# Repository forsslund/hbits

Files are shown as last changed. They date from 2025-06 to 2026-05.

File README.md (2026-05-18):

# Haptic Bits Lab Repository
here you find all the necessary files to be able to eithe build your own or repair a Haptic Bit. If you want to know more what a haptic bit is or the Haptic Bits Lab, have a look here: (https://hbits.forsslundsystems.com)

## Software Recommendation for MIDI Recording
The are myriads of choices of MIDI recording software. Here's a list of some that work great with the bits:
- Chataigne: A multipurpose sequencer that also supports MIDI. You'll find a template in the folder "MIDI". It's configured to record all bits in one kit. https://benjamin.kuperberg.fr/chataigne/en
- Signal: Online MIDI sequencer that runs great on Chrome (note: doesn't work with Safari): https://signalmidi.app/edit
- MIDI Bitslab: Our own attempt of a recording environment that runs great on Chrome (note: doesn't work with Safari). It emphasises sketching and direct recording and has some features to make dynamic patches. : https://github.com/somaBits/Midi_BitLab/

## Firmware
The bits are driven by an ESP32. If you would like to make changes to the firmware you are free to download this repository and open it in VS code with the platform.io plugin.

This can be usefull if for example you wish to customise the haptic patterns for the vibration bits.

## Do it Yourself
The Haptic Bits Lab is designed to be built by anyone that has access to a 3D printer and laser cutter. The carrier PCB are produced by PCBway and can be order semi-populated with SMD parts via this link: (https://www.pcbway.com/project/shareproject/Haptic_Bits_Lab_Carrier_PCB_semi_populated_7a38576c.html)

This Bill of material contains all the third-party parts needed to create the bits: (https://docs.google.com/spreadsheets/d/1yp4ojiJQZM4SgLv2cJ91fp2alQbMcc3hZMMRH2068LM/edit?usp=sharing)

The 3D model of the enclosure are modelled in Fusion 360 and can be downloaded here:

|Name | Link | Image |
| --- | --- | --- |
| AIR enclosure | https://a360.co/3LH06NW or [3MF file for printing ](hardware/3d_models/HBL_AIR.3mf)| AIR |
| VIBE / HEAT enclosure | https://a360.co/4b2XGnf or [3MF file for printing ](hardware/3d_models/HBL_VIBEHEAT.3mf) | VIBE:HEAT |
| Rotary Knob | https://a360.co/4jEkBaE or [3MF file for printing ](hardware/3d_models/HBL KNOBS_6x.3mf) | Knob |
| LED Ring Support | https://a360.co/4jEkBaE or [3MF file for printing ](hardware/3d_models/HBL_RING_SUPPORT.3mf) | LED support |
| USB-C Support | https://a360.co/4qu6h79  or [3MF file for printing ](hardware/3d_models/HBL_USB_SUPPORT.3mf) | USB-C Support |
| VIBE Puck | https://a360.co/3NGZx7i  or [3MF file for printing ](hardware/3d_models/HBL_PUCK.3mf) | VIBE Puck |

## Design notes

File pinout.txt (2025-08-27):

ESP32 nano Compatible

NEW

Pin (GPIO)
21   CLK  Incremental encoder A
38   DT   Incremental encoder B
47   D12   Encoder Switch
11   SDA  I2c
12   SCL  I2c
1    A0   Force Sensitive Resistor
18   D9   Mosfet PWM control 1
17   D8   Mosfet PWM control 2
10   D7   Mosfet PWM control 3
9    D6   Mosfet PWM control 4

I2C to 
- LED Ring
- Haptic driver
- USB C PD (not really used) --> maybe for Current control

MOSFET Motor pinout
const uint8_t MOTOR_PINS[4] = {18, 17, 10, 9};  // GPIO pins for motors

OLD

Pin (GPIO)
5   CLK  Incremental encoder A
6   DT   Incremental encoder B
23  SDA  I2c
24  SCL  I2c
19  A0   Force Sensitive Resistor
9   D6   Mosfet PWM control 1
10  D7   Mosfet PWM control 2
11  D8   Mosfet PWM control 3
12  D9   Mosfet PWM control 4

I2C to 
- LED Ring
- Haptic driver
- USB C PD (not really used)

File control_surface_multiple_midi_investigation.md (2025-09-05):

# Control Surface Library Multiple MIDI Message Investigation

## Issue Summary

The Control Surface library generates multiple consecutive MIDI CC messages from a single analog input change, creating what appears to be "interpolated" values between readings. This investigation aimed to understand whether this behavior originates from the library itself or external tools.

## Initial Question

**"Do Control Surface or the potentiometer class ADD messages which interpolate between readings?"**

The user observed consecutive CC22 values (25→26→27→28→29→30...) in MIDI recordings even with a 100ms delay in the main loop, questioning whether this interpolation came from:
1. The Control Surface library
2. The signalmidi.app web-based MIDI tool

## Investigation Methodology

### 1. Code Analysis
- Examined `CCPotentiometer.hpp` - Simple wrapper around `MIDIFilteredAnalog`
- Analyzed `MIDIFilteredAnalog.hpp` - Uses `FilteredAnalog` with EMA filtering and hysteresis
- Investigated `FilteredAnalog.hpp` - Complex filtering system with multiple internal states
- Checked `ContinuousCCSender.hpp` - Simple single-message sender

### 2. Debug Implementation
Added comprehensive logging to track:
- Raw analog readings from `analogRead(A0)`
- MIDI message transmission with sequence numbers
- Millisecond and microsecond timestamps

### 3. Test Results Analysis
Debug output revealed the key findings with clear evidence.

## Key Findings

### **CONFIRMED: Control Surface Library DOES Generate Multiple MIDI Messages**

The debug output definitively proved that multiple MIDI messages originate from the ESP32, not from external tools:

```
[RAW] A0: 667 @ 17974ms / 17974878μs
[ESP32 TX #208] CC22: 28 (vol=0.220) @ 17975ms / 17975344μs
[ESP32 TX #209] CC22: 41 (vol=0.323) @ 17975ms / 17975691μs
[ESP32 TX #210] CC22: 39 (vol=0.307) @ 17975ms / 17975979μs
```

**Evidence:**
- Single analog reading produces multiple MIDI messages
- Sequential message counters prove no routing duplication
- Microsecond timestamps show rapid consecutive transmission
- Pattern consistent across all test scenarios

### **Root Cause: EMA Filter + Hysteresis System**

The Control Surface library's `FilteredAnalog` class implements:
1. **Exponential Moving Average (EMA) filtering** for noise reduction
2. **Hysteresis** to prevent value oscillation
3. **Internal state buffering** that can generate multiple discrete outputs from one analog input

When analog values change rapidly (e.g., releasing FSR pressure), the filtering algorithm creates multiple state transitions that each cross hysteresis thresholds, triggering separate MIDI messages.

## Technical Details

### Library Architecture
```
CCPotentiometer → MIDIFilteredAnalog → FilteredAnalog → EMA + Hysteresis → Multiple MIDI outputs
```

### Filter Parameters (Default)
- **Filter Shift Factor**: `ANALOG_FILTER_SHIFT_FACTOR` (typically 2-4)
- **Filter Type**: `ANALOG_FILTER_TYPE` (usually uint16_t)
- **Precision**: 7-bit for standard CC messages
- **Hysteresis**: Applied after filtering to prevent jitter

### Message Flow
1. `analogRead(A0)` provides raw input
2. EMA filter processes the reading
3. Mapping function applied (if any)
4. Hysteresis determines if change is significant
5. Multiple threshold crossings → Multiple MIDI messages
6. All messages sent within same `Control_Surface.loop()` call

## Solutions Identified

### Option 1: Adjust Filter Parameters
**Approach**: Modify Control Surface library settings
- Create custom `Settings.hpp` with `ANALOG_FILTER_SHIFT_FACTOR = 0`
- Reduces or eliminates EMA filtering
- Keeps basic hysteresis for stability

### Option 2: Custom Analog Input Class
**Approach**: Bypass FilteredAnalog system entirely
- Direct `analogRead()` implementation
- Custom simple filtering/debouncing
- Single MIDI message per significant change

### Option 3: Rate Limiting in MIDI Sink
**Approach**: Throttle output in `HapticVolumeSink`
```cpp
static unsigned long lastMidiTime = 0;
unsigned long now = millis();
if (now - lastMidiTime < 50) return; // Ignore messages < 50ms apart
lastMidiTime = now;
```

### Option 4: Simple Analog Reading
**Approach**: Replace CCPotentiometer entirely
- Manual analog reading in main loop
- Direct MIDI sending
- Complete bypass of Control Surface filtering

## Recommendations

### For Quick Fix
**Option 3 (Rate Limiting)** - Easiest implementation, maintains existing architecture

### For Optimal Control
**Option 1 (Filter Parameter Adjustment)** - Addresses root cause while preserving library benefits

### For Maximum Simplicity
**Option 4 (Manual Implementation)** - Full control but loses library advantages

## Implementation Status

- **Investigation**: ✅ Complete
- **Debug Tools**: ✅ Implemented
- **Root Cause**: ✅ Identified
- **Solutions**: ✅ Designed
- **Implementation**: ❌ Deferred

## Files Modified During Investigation

- `src/main.cpp` - Enhanced with comprehensive debug logging
  - Message sequence counters
  - Raw analog value tracking
  - Microsecond timing precision

## Next Steps

1. Choose preferred solution approach
2. Implement selected option
3. Test with FSR to verify behavior change
4. Remove debug logging if desired
5. Document final solution in code comments

## Technical Notes

- Standard MIDI does not include timestamps
- Multiple messages can be sent within same millisecond
- Control Surface pipe routing does not cause duplication
- EMA filtering is fundamental to Control Surface stability
- Completely disabling filtering may introduce noise/jitter

---

**Investigation Date**: January 2025  
**Library Version**: Control Surface (latest from GitHub main branch)  
**Hardware**: Arduino Nano ESP32  
**Conclusion**: Control Surface library intentionally generates multiple MIDI messages through its sophisticated filtering system - this is normal operation, not a bug.

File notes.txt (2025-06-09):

LED Examples

  /*

  /*
static uint8_t j = 0;
static uint8_t i = 0;
static uint16_t tim = 0;
static uint8_t r = 5, g = 8, b = 20, rg = 40, br = 35, bg = 17;
const  uint32_t fade1_table[24] = {0x8011EE, 0xA004DA,  0xBF00BF, 0xDA04A0, 0xEE1180, 0xFB255F, 0xFF4040, 0xFB5F25, 0xEE8011, 0xDAA004, 0xBFBF00, 0xA0DA04, 0x80EE11, 0x5FFB25, 0x40FF40, 0x25FB5F, 0x11EE80, 0x04DAA0, 0x00BFBF, 0x04A0DA, 0x1180EE, 0x255FFB, 0x4040FF, 0x5F25FB};
const  uint32_t fade2_table[24] = {0xFF0000, 0xFF0004,  0xFF0020, 0xFF006B, 0xFF00FF, 0x6B00FF, 0x2000FF, 0x0400FF, 0x0000FF, 0x0004FF, 0x0020FF, 0x006BFF, 0x00FFFF, 0x00FF6B, 0x00FF20, 0x00FF04, 0x00FF00, 0x04FF00, 0x20FF00, 0x6BFF00, 0xFFFF00, 0xFF6B00, 0xFF2000, 0xFF0400};

*/

  for (i = 0; i < 24; i++) {
    ledRing.LEDRingSmall_Set_RED(i, 0);
    ledRing.LEDRingSmall_Set_GREEN(i, 0xff);
    delay(30);
  }

  for (i = 0; i < 24; i++) {
    ledRing.LEDRingSmall_Set_GREEN(i, 0);
    ledRing.LEDRingSmall_Set_BLUE(i, 0xff);
    delay(30);
  }

  for (i = 0; i < 24; i++) {

    ledRing.LEDRingSmall_Set_RGB(i, 0xfc6b03);
    delay(30);
  }

  for (i = 0; i < 24; i++) {

    ledRing.LEDRingSmall_Set_RGB(i, 0xfc03c6);
    delay(30);
  }
//  delay(2000);
  //LEDRingSmall.LEDRingSmall_ClearAll();

  for (tim = 0; tim < 2000; tim++) {

    if ((tim % 5) == 0) {
      ledRing.LEDRingSmall_Set_RED(r, 0);
      r = r + 1;
      if (r >= 24)
        r = 0;
      ledRing.LEDRingSmall_Set_RED(r, 0xFF);
    }

    if ((tim % 6) == 0) {
      ledRing.LEDRingSmall_Set_GREEN(g, 0);
      g = g + 1;
      if (g >= 24)
        g = 0;
      ledRing.LEDRingSmall_Set_GREEN(g, 0xFF);
    }

    if ((tim % 8) == 0) {
      ledRing.LEDRingSmall_Set_BLUE(b, 0);
      b = b + 1;
      if (b >= 24)
        b = 0;
      ledRing.LEDRingSmall_Set_BLUE(b, 0xFF);
    }

    if ((tim % 7) == 0) {
      ledRing.LEDRingSmall_Set_BLUE(br, 0);
      ledRing.LEDRingSmall_Set_RED(br, 0);
      br = br + 1;
      if (br >= 24)
        br = 0;
      ledRing.LEDRingSmall_Set_BLUE(br, 0xFF);
      ledRing.LEDRingSmall_Set_RED(br, 0xFF);
    }

    if ((tim % 10) == 0) {
      ledRing.LEDRingSmall_Set_BLUE(bg, 0);
      ledRing.LEDRingSmall_Set_GREEN(bg, 0);
      bg = bg + 1;
      if (bg >= 24)
        bg = 0;
      ledRing.LEDRingSmall_Set_BLUE(bg, 0xFF);
      ledRing.LEDRingSmall_Set_GREEN(bg, 0xFF);
    }

    if ((tim % 11) == 0) {
      ledRing.LEDRingSmall_Set_RED(rg, 0);
      ledRing.LEDRingSmall_Set_GREEN(rg, 0);
      rg = rg + 1;
      if (rg >= 24)
        rg = 0;
      ledRing.LEDRingSmall_Set_RED(rg, 0xFF);
      ledRing.LEDRingSmall_Set_GREEN(rg, 0xFF);
    }

    delay(10);
  }

  for (tim = 0; tim < 100; tim++) {
    j = tim % 24;

    for (i = 0; i < 24; i++) {
      ledRing.LEDRingSmall_Set_RGB(i, fade1_table[j]);
      j++;
      if (j >= 24)
        j = 0;
    }
    delay(40);
  }

  for (tim = 0; tim < 100; tim++) {
    j = tim % 24;
    for (i = 0; i < 24; i++) {
      ledRing.LEDRingSmall_Set_RGB(i, fade2_table[j]);
      j++;
      if (j >= 24)
        j = 0;
    }
    delay(40);
  }

  for (i = 0xff; i > 0; i--) {

    ledRing.LEDRingSmall_GlobalCurrent(i);
    delay(20);
  }
  ledRing.LEDRingSmall_ClearAll();
  ledRing.LEDRingSmall_GlobalCurrent(0xff);
*/

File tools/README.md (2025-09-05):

# MIDI CC22 Parser

A Node.js tool for parsing MIDI files and extracting Control Change messages for controller 22 (CC22) with accurate timestamps.

## Overview

This tool parses the `haptic.mid` file in the project root and extracts all CC22 (Control Change controller 22) messages, displaying them with precise timestamps in milliseconds.

## Features

- Parses Standard MIDI files (Format 0 and 1)
- Extracts CC22 control change messages specifically
- Calculates accurate timestamps from MIDI ticks
- Handles tempo changes for precise timing
- Displays results in a readable format with timestamps

## Installation

```bash
cd tools
npm install
```

## Usage

### Run the parser:
```bash
cd tools
node midi-parser.js
```

### Or use npm script:
```bash
cd tools
npm start
```

## Output Format

The tool outputs:
- MIDI file information (format, tracks, time division)
- Track-by-track analysis
- CC22 messages with timestamps in format `[M:SS.mmm] CC22 (Channel X): value`
- Summary with total count of CC22 messages found

### Example Output:
```
MIDI CC22 Parser
================
Parsing MIDI file: /home/jonas/hbits/haptic.mid
MIDI Format: 1
Tracks: 2
Time division: 480 ticks per quarter note

=== Track 0 ===
[0:00.000] Tempo change: 120 BPM

=== Track 1 ===
[0:00.550] CC22 (Channel 0): 1
[0:00.550] CC22 (Channel 0): 2
[0:00.660] CC22 (Channel 0): 3
...

=== Summary ===
Total CC22 messages found: 378
```

## Technical Details

### MIDI CC22
- CC22 refers to Control Change messages with controller number 22
- These are MIDI messages with status bytes 0xB0-0xBF (control change)
- Data byte 1 = 22 (controller number)
- Data byte 2 = 0-127 (controller value)

### Timestamp Calculation
- Converts MIDI ticks to milliseconds using the file's time division
- Accounts for tempo changes throughout the file
- Default tempo: 120 BPM (500,000 microseconds per quarter note)
- Formula: `(ticks × microsecondsPerQuarter) / timeDivision / 1000`

### Dependencies
- `midi-file`: Lightweight MIDI file parser for Node.js

## File Structure
```
tools/
├── package.json          # Node.js project configuration
├── midi-parser.js         # Main parser script
└── README.md             # This documentation
```

## Requirements
- Node.js (any recent version)
- The `haptic.mid` file in the project root directory

## Notes
- The tool automatically looks for `haptic.mid` in the parent directory
- If no CC22 messages are found, the tool will notify you
- The parser handles both tempo changes and multiple tracks correctly

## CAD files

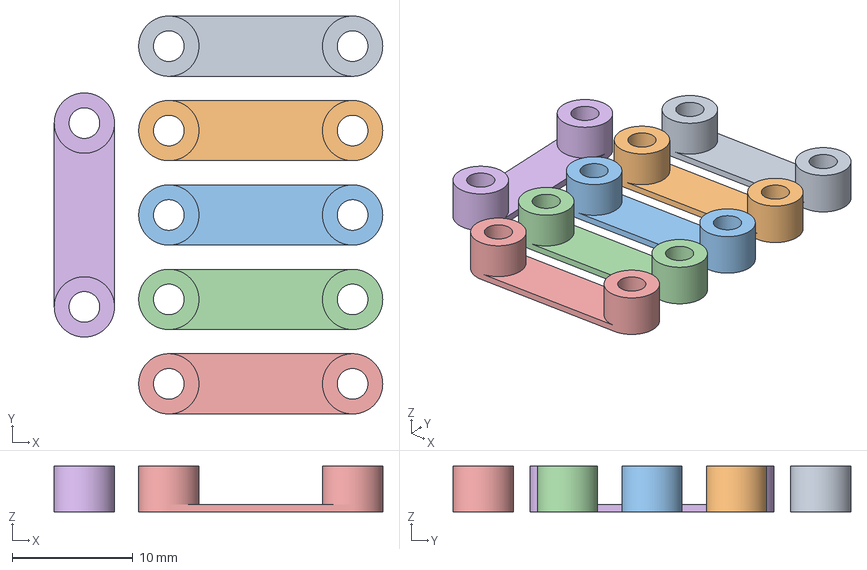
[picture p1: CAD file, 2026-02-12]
hardware/3d_models/HBL_USB_SUPPORT.3mf
27.2 x 33.0 x 3.80 mm
HBL_USB_SUPPORT x 6

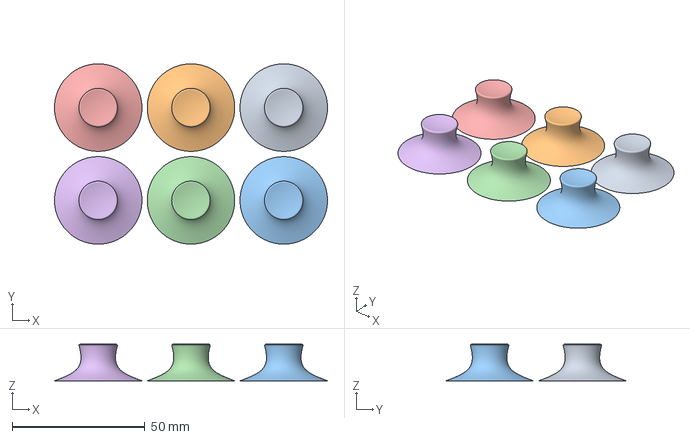
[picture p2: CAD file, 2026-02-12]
hardware/3d_models/HBL KNOBS_6x.3mf
103.0 x 68.0 x 13.8 mm
HBL_KNOBS_x6

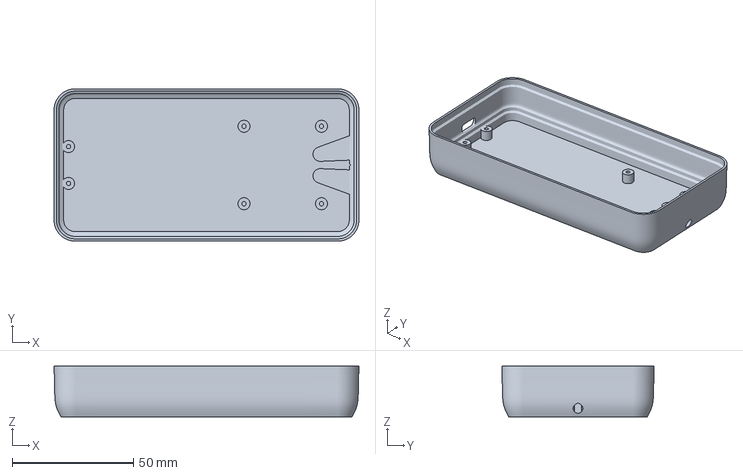
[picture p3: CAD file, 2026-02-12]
hardware/3d_models/HBL_VIBEHEAT.3mf
126.0 x 63.0 x 21.0 mm

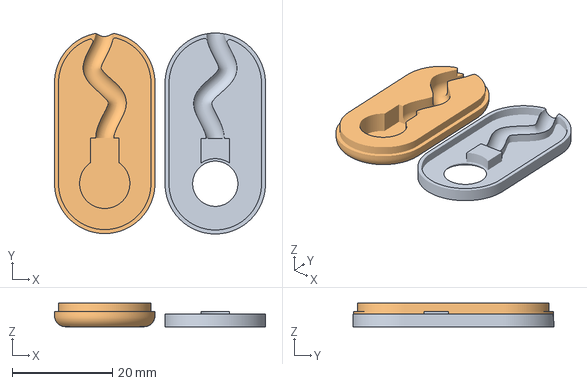
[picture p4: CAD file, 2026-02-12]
hardware/3d_models/HBL_PUCK.3mf
42.0 x 40.0 x 4.70 mm
HBL_PUCK

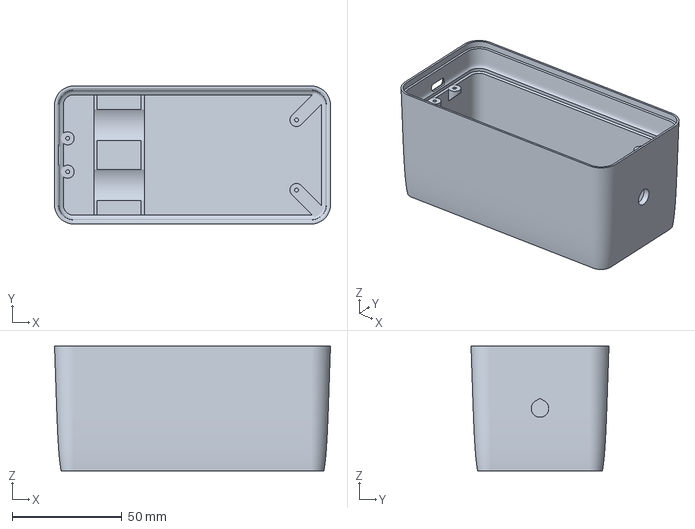
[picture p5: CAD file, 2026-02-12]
hardware/3d_models/HBL_AIR.3mf
126.0 x 63.0 x 57.0 mm

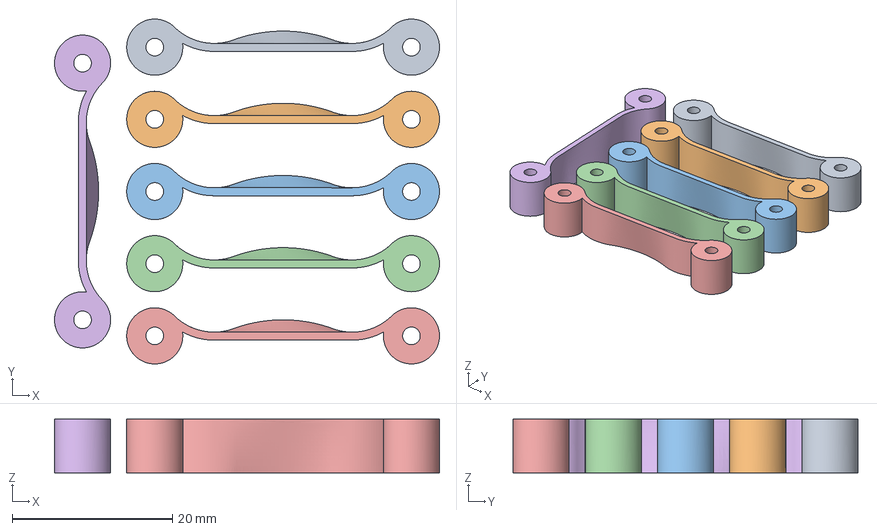
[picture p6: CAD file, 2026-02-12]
hardware/3d_models/HBL_RING_SUPPORT.3mf
48.0 x 43.0 x 6.70 mm
HBL_RING_SUPPORT x 6

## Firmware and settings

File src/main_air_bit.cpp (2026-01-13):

#include <Arduino.h>
#include <Control_Surface.h>
#include <Wire.h>
#include <Adafruit_LPS28.h>
#include "cli.h"
#include "ledcontrol.h"

// MIDI Interface
BluetoothMIDI_Interface midibt;

// CLI Interface
CLI commandInterface(Serial, midibt);

// LED Controller
LEDController ledController;

// 4 MOSFET pump/valve control setup
const uint8_t MOTOR_PINS[4] = {18, 17, 10, 9};  // GPIO pins for motors: M1 pump inflate, M2 pump deflate, M3 valve inflate, M4 valve deflate
const uint8_t PWM_CHANNELS[4] = {0, 1, 2, 3};   // PWM channels for motors
volatile uint8_t currentAirLevel = 64; // Current air level (0-127, with 64 = stopped)

// Air Control Encoder - sends CC24 MIDI messages
CCAbsoluteEncoder airEncoder {
    {38, 21},  // Encoder pins (swapped for clockwise increase)
    {24},       // CC 24 for air control
    6           // Multiplier
};

// Encoder Reset Button - connected to D12 (GPIO 47)
Button encoderResetButton {47};

// LPS28 Pressure Sensor Setup - using Adafruit LPS28 library
Adafruit_LPS28 lps28;  // LPS28 sensor object using Adafruit library
unsigned long lastPressureRead = 0;
float currentPressure = 0.0;
uint8_t pressureMidiValue = 0;

// Use default I2C pins (GPIO 21 = SDA, GPIO 22 = SCL)
// These work fine alongside encoder and other I2C devices

// Pressure Output - we'll send CC25 directly via MIDI interface

/**
 * @brief Custom MIDI sink for air/pump control
 * 
 * This sink receives MIDI messages from pipes and controls the air pressure
 * based on CC 24 messages with 64-centered mapping:
 * - CC 62-66: Stop (all motors off)
 * - CC 65-127: Inflation (increasing PWM)
 * - CC 0-63: Deflation (increasing PWM)
 */
class AirControlSink : public TrueMIDI_Sink {
public:
    AirControlSink() {}
    
    void sinkMIDIfromPipe(ChannelMessage msg) override {
        // Handle CC 24 messages for air control
        if (msg.getMessageType() == MIDIMessageType::ControlChange && 
            msg.getData1() == 24) {
            
            uint8_t ccValue = msg.getData2();
            currentAirLevel = ccValue;
            
            if (ccValue <= 66 && ccValue >= 62) {
                // Stop - all motors off
                for (int i = 0; i < 4; i++) {
                    ledcWrite(PWM_CHANNELS[i], 0);
                }
                Serial.println("Air control: STOPPED (CC24=64)");
                
            } else if (ccValue > 66) {
                // Inflation mode (67-127)
                uint8_t pwmValue = map(ccValue, 67, 127, 0, 255);
                
                // M1 pump inflate (ON), M2 pump deflate (OFF)
                ledcWrite(PWM_CHANNELS[0], pwmValue);  // M1 (GPIO 18)
                ledcWrite(PWM_CHANNELS[1], 0);         // M2 (GPIO 17)
                
                // M3 valve inflate (ON), M4 valve deflate (OFF)
                ledcWrite(PWM_CHANNELS[2], 255);  // M3 (GPIO 10)
                ledcWrite(PWM_CHANNELS[3], 0);         // M4 (GPIO 9)
                
                Serial.print("Air control: INFLATING ");
                Serial.print(((ccValue - 64) * 100) / 63);
                Serial.print("% (CC24=");
                Serial.print(ccValue);
                Serial.print(", PWM=");
                Serial.print(pwmValue);
                Serial.println(")");
                
            } else if(ccValue < 62) {
                // Deflation mode (0-61)
                uint8_t pwmValue = map(ccValue, 0, 61, 255, 0);
                
                // M1 pump inflate (OFF), M2 pump deflate (ON)
                ledcWrite(PWM_CHANNELS[0], 0);         // M1 (GPIO 18)
                ledcWrite(PWM_CHANNELS[1], pwmValue);  // M2 (GPIO 17)
                
                // M3 valve inflate (OFF), M4 valve deflate (ON)
                ledcWrite(PWM_CHANNELS[2], 0);         // M3 (GPIO 10)
                ledcWrite(PWM_CHANNELS[3], 255);  // M4 (GPIO 9)
                
                Serial.print("Air control: DEFLATING ");
                Serial.print(((63 - ccValue) * 100) / 63);
                Serial.print("% (CC24=");
                Serial.print(ccValue);
                Serial.print(", PWM=");
                Serial.print(pwmValue);
                Serial.println(")");
            }
        }
    }
    
    // Required overrides for other MIDI message types (no-op for our use case)
    void sinkMIDIfromPipe(SysExMessage) override {}
    void sinkMIDIfromPipe(SysCommonMessage) override {}
    void sinkMIDIfromPipe(RealTimeMessage) override {}
};

// Instantiate the air control sink
AirControlSink airSink;

/**
 * @brief MIDI Routing Setup
 * 
 * Creates a clean pipe-based routing system with three explicit routes:
 * 
 *  ┌─────────────────┐    ┌──────────────┐    ┌─────────────────┐
 *  │ Air Encoder     │───▶│ Control_     │───▶│ Bluetooth Out   │ Route 1
 *  │ CC 24           │    │ Surface      │    │ (transmission)  │
 *  └─────────────────┘    └──────────────┘    └─────────────────┘
 *                                                       ▲
 *                                                       │ Route 2
 *  ┌─────────────────┐    ┌──────────────┐             │
 *  │ External MIDI   │───▶│ Bluetooth In │─────────────┘
 *  │ Controller      │    │ CC24 → Air   │
 *  └─────────────────┘    └──────────────┘
 *                         
 *  ┌─────────────────┐    ┌──────────────┐
 *  │ Air Encoder     │───▶│ AirSink      │ Route 3
 *  │ CC 24           │    │ (direct)     │
 *  └─────────────────┘    └──────────────┘
 */

// Pipe factory for proper routing management (need 2 pipes for separation of concerns)
MIDI_PipeFactory<3> pipeFactory;

/**
 * @brief Update pressure reading and send CC25 MIDI message
 * 
 * Uses status-based reading following official Adafruit patterns.
 * Only reads when data is ready, more efficient than timer-based polling.
 * Initial mapping: 950-1050 hPa → 0-127 MIDI range (adjustable based on actual readings)
 */
void updatePressureReading() {
    // Check if pressure data is ready using official Adafruit pattern
    if (lps28.getStatus() & LPS28_STATUS_PRESS_READY) {
        // Read pressure and temperature directly using official methods
        float pressureHPa = lps28.getPressure();
        float temperatureC = lps28.getTemperature();
        currentPressure = pressureHPa;
        
        // Map pressure to MIDI range (measured range: 880-1250 hPa)
        // Constrain to prevent wraparound below minimum pressure
        long pressureCentiPa = (long)(pressureHPa * 100);
        pressureMidiValue = map(pressureCentiPa, 88000, 175000, 0, 127);
        pressureMidiValue = constrain(pressureMidiValue, 0, 127);
        
        // Send CC25 MIDI message directly
        midibt.sendControlChange({25, Channel_1}, pressureMidiValue);
        
        // Throttle serial output to avoid flooding (only every 100ms)
        if (millis() - lastPressureRead >= 100) {
            Serial.print("Pressure: ");
            Serial.print(currentPressure, 2);
            Serial.print(" hPa, Temp: ");
            Serial.print(temperatureC, 1);
            Serial.print(" °C, MIDI CC25: ");
            Serial.println(pressureMidiValue);
            lastPressureRead = millis();
        }
    }
}

void setup() {
    Serial.begin(115200);
    Serial.println("=== HBITS Air Controller ===");
    
    // Initialize PWM channels for 4 MOSFET pump/valve control
    Serial.println("Initializing PWM for pump/valve motors...");
    for (int i = 0; i < 4; i++) {
        ledcSetup(PWM_CHANNELS[i], 1000, 8); // 1kHz, 8-bit resolution
        ledcAttachPin(MOTOR_PINS[i], PWM_CHANNELS[i]);
        ledcWrite(PWM_CHANNELS[i], 0); // Start with all motors off
    }
    Serial.println("PWM channels initialized for pump/valve control");
    
    // Initialize I2C for LPS28 pressure sensor (default pins work fine with encoder)
    Serial.println("Initializing I2C for LPS28 pressure sensor...");
    Wire.begin();  // Use default I2C pins (GPIO 21 = SDA, GPIO 22 = SCL)
    
    // I2C device scanning with delay as requested
    Serial.println("Scanning I2C devices...");
    //delay(5000);  // 5 second delay so user doesn't miss I2C device detection messages
    int deviceCount = 0;
    for (byte address = 1; address < 127; address++) {
        Wire.beginTransmission(address);
        if (Wire.endTransmission() == 0) {
            Serial.print("I2C device found at address 0x");
            if (address < 16) Serial.print("0");
            Serial.println(address, HEX);
            deviceCount++;
        }
    }
    if (deviceCount == 0) {
        Serial.println("No I2C devices found");
    } else {
        Serial.print("Found ");
        Serial.print(deviceCount);
        Serial.println(" I2C device(s)");
    }
    
    // Try to initialize LPS28 with the detected I2C address 0x5C  
    if (!lps28.begin(&Wire, 0x5C)) {
        Serial.println("Failed to initialize LPS28 chip at address 0x5C");
        Serial.println("Continuing without pressure sensor...");
        // Don't halt - continue without pressure sensor
    } else {
        Serial.println("LPS28 Found and initialized at address 0x5C!");
        
        // Configure sensor for optimal accuracy and stability
        lps28.setDataRate(LPS28_ODR_10_HZ);
        lps28.setAveraging(LPS28_AVG_4);        // 4-sample averaging for noise reduction
        lps28.setFullScaleMode(true);           // Extended range (4060 hPa) for better resolution
        
        Serial.println("LPS28 pressure sensor configured:");
        Serial.println("  - Data rate: 10 Hz");
        Serial.println("  - Averaging: 4 samples (noise reduction)");
        Serial.println("  - Full-scale mode: Extended range (4060 hPa)");
        Serial.println("LPS28 pressure sensor ready!");
    }
    
    // Set up clean pipe-based routing BEFORE Control_Surface.begin()
    // Three explicit, unidirectional routes for clear separation of concerns:
    
    // Route 1: Control_Surface (Air Encoder) → Bluetooth (CC23 transmission)
    Control_Surface >> pipeFactory >> midibt;
    
    // Route 2: Bluetooth → AirSink (external MIDI control of air)
    midibt >> pipeFactory >> airSink;
    
    // Route 3: Control_Surface → AirSink (direct encoder control)
    Control_Surface >> pipeFactory >> airSink;
    
    // Set Bluetooth device name
    midibt.setName("AIR bit 1 MST");
    
    // Initialize LED controller
    ledController.begin();
    
    // Initialize the Control Surface system
    Control_Surface.begin();
    encoderResetButton.begin(); // Initialize encoder reset button.
    
    // Initialize encoder to center position (64)
    airEncoder.setValue(64);
    Serial.println("Air encoder initialized to center position (CC24=64)");
            
    // Initialize CLI
    commandInterface.begin();
    
    Serial.println("Routing configured:");
    Serial.println("  Route 1: Air Encoder → CC24 → Bluetooth Out (transmission)");
    Serial.println("  Route 2: Bluetooth In → CC24 → Air Control (external control)");
    Serial.println("  Route 3: Air Encoder → CC24 → Air Control (direct control)");
    Serial.println("  Route 4: LPS28 Pressure Sensor → CC25 → Bluetooth Out (every 100ms)");
    Serial.println("  Route 5: Encoder Reset Button → D12 (GPIO 47) → Emergency Stop");
    Serial.println("Ready!");
}

void loop() {
    // Update all MIDI processing and routing
    Control_Surface.loop();
    delay(5); // Limit control surface processing.
    
    digitalWrite(LED_BUILTIN, midibt.isConnected() ? HIGH : LOW);

    // Check for encoder reset button press
    if (encoderResetButton.update() && encoderResetButton.getState() == Button::Falling) {
        // Reset encoder to center position (64) - stops pump
        airEncoder.setValue(64);
        currentAirLevel = 64;
        
        // Immediately stop all motors
        for (int i = 0; i < 4; i++) {
            ledcWrite(PWM_CHANNELS[i], 0);
        }
        
        Serial.println("ENCODER RESET BUTTON PRESSED - Pump stopped (CC24=64)");
    }

    // Update pressure reading and send CC25
    updatePressureReading();

    // Update LED display to show current air level with center-based visualization
    ledController.updateAirDisplay(currentAirLevel);
    
    // Refresh LED display
    ledController.refresh();
    
    // Handle CLI interface
    commandInterface.update();
}

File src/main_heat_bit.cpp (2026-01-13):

#include <Arduino.h>
#include <Control_Surface.h>
#include <Adafruit_INA219.h>
#include "cli.h"
#include "ledcontrol.h"

// MIDI Interface
BluetoothMIDI_Interface midibt;

// CLI Interface
CLI commandInterface(Serial, midibt);

// LED Controller
LEDController ledController;

// INA219 Current Sensor
Adafruit_INA219 ina219;

// Heat control PWM setup
const uint8_t HEAT_PIN = 18;        // GPIO pin for MOSFET M1
const uint8_t HEAT_PWM_CHANNEL = 0; // PWM channel for heat control
volatile uint8_t currentHeatLevel = 0; // Current heat level (0-127)

// Timing for INA219 readings
unsigned long lastINA219Reading = 0;
const unsigned long INA219_INTERVAL = 50; // Read every 50ms

// Power limiting variables
const float MAX_POWER_W = 8.0; // Maximum allowed power in watts
uint8_t maxAllowedHeatLevel = 127; // Auto-discovered power limit (starts at max)
float averagePower = 0.0; // Running average power
bool powerLimitActive = false; // Flag to indicate if power limiting is active

// Heat Control Encoder - sends CC23 MIDI messages
CCAbsoluteEncoder heatEncoder {
    {38, 21},  // Encoder pins (swapped for clockwise increase)
    {23},       // CC 23 for heat control
    6           // Multiplier
};

/**
 * @brief Custom MIDI sink for heat control
 * 
 * This sink receives MIDI messages from pipes and controls the heat level
 * based on CC 23 messages. It follows the TrueMIDI_Sink interface properly.
 */
class HeatControlSink : public TrueMIDI_Sink {
public:
    HeatControlSink() {}
    
    void sinkMIDIfromPipe(ChannelMessage msg) override {
        // Handle CC 23 messages for heat control
        if (msg.getMessageType() == MIDIMessageType::ControlChange && 
            msg.getData1() == 23) {
            
            uint8_t requestedHeatLevel = msg.getData2();
            
            // Apply power limiting: clamp to discovered maximum
            currentHeatLevel = min(requestedHeatLevel, maxAllowedHeatLevel);
            
            // Convert CC23 value (0-127) to PWM duty cycle (0-255)
            uint8_t pwmValue = (currentHeatLevel * 255) / 127;
            ledcWrite(HEAT_PWM_CHANNEL, pwmValue);
            
            // Check if power limiting is active
            if (requestedHeatLevel > maxAllowedHeatLevel) {
                powerLimitActive = true;
            } else {
                powerLimitActive = false;
            }
            
            Serial.print("Heat level: ");
            Serial.print((currentHeatLevel * 100) / 127);
            Serial.print("% (CC23=");
            Serial.print(currentHeatLevel);
            if (powerLimitActive) {
                Serial.print(" POWER LIMITED from ");
                Serial.print(requestedHeatLevel);
            }
            Serial.print(", PWM=");
            Serial.print(pwmValue);
            Serial.println(")");
        }
    }
    
    // Required overrides for other MIDI message types (no-op for our use case)
    void sinkMIDIfromPipe(SysExMessage) override {}
    void sinkMIDIfromPipe(SysCommonMessage) override {}
    void sinkMIDIfromPipe(RealTimeMessage) override {}
};

// Structure to hold averaged sensor readings
struct AveragedReadings {
    float current_A;
    float voltage_V;
    float power_W;
};

// Function to get averaged readings from multiple samples
AveragedReadings getAveragedReadings(int numSamples = 10) {
    float totalCurrent = 0.0;
    float totalVoltage = 0.0;
    float totalPower = 0.0;
    
    for (int i = 0; i < numSamples; i++) {
        totalCurrent += ina219.getCurrent_mA();
        totalVoltage += ina219.getBusVoltage_V();
        totalPower += ina219.getPower_mW();
        delay(1); // Small delay between samples
    }
    
    AveragedReadings readings;
    readings.current_A = (totalCurrent / numSamples) / 1000.0; // Convert mA to A
    readings.voltage_V = totalVoltage / numSamples;
    readings.power_W = (totalPower / numSamples) / 1000.0; // Convert mW to W
    
    return readings;
}

// Instantiate the heat control sink
HeatControlSink heatSink;

/**
 * @brief MIDI Routing Setup
 * 
 * Creates a clean pipe-based routing system with two explicit routes:
 * 
 *  ┌─────────────────┐    ┌──────────────┐    ┌─────────────────┐
 *  │ Heat Encoder    │───▶│ Control_     │───▶│ Bluetooth Out   │ Route 1
 *  │ CC 23           │    │ Surface      │    │ (transmission)  │
 *  └─────────────────┘    └──────────────┘    └─────────────────┘
 *                                                       ▲
 *                                                       │ Route 2
 *  ┌─────────────────┐    ┌──────────────┐             │
 *  │ External MIDI   │───▶│ Bluetooth In │─────────────┘
 *  │ Controller      │    │ CC23 → Heat  │
 *  └─────────────────┘    └──────────────┘
 */

// Pipe factory for proper routing management (need 2 pipes for separation of concerns)
MIDI_PipeFactory<3> pipeFactory;

void setup() {
    Serial.begin(115200);
    Serial.println("=== HBITS Heat Controller ===");
    
    // Initialize PWM for heat control
    ledcSetup(HEAT_PWM_CHANNEL, 1000, 8); // 1kHz, 8-bit resolution
    ledcAttachPin(HEAT_PIN, HEAT_PWM_CHANNEL);
    ledcWrite(HEAT_PWM_CHANNEL, 0); // Start with heat off
    
    Serial.println("PWM heat control initialized on pin 18");
    
    // Initialize INA219 current sensor
    if (!ina219.begin()) {
        Serial.println("ERROR: Failed to find INA219 sensor!");
        Serial.println("Check wiring and I2C address (default 0x40)");
    } else {
        Serial.println("INA219 current sensor initialized");
        // Optional: set calibration for higher precision if needed
        // ina219.setCalibration_32V_2A();  // 32V, 2A max (default)
        // ina219.setCalibration_32V_1A();  // 32V, 1A max (higher precision)
        // ina219.setCalibration_16V_400mA(); // 16V, 400mA max (highest precision)
    }
    
    // Set up clean pipe-based routing BEFORE Control_Surface.begin()
    // Two explicit, unidirectional routes for clear separation of concerns:
    // 

    // Route 1: Control_Surface (FSR) → HeatSink (standalone haptic control)
    Control_Surface >> pipeFactory >> heatSink;
    
    // Route 2: Control_Surface (Heat Encoder) → Bluetooth (CC23 transmission)
    Control_Surface >> pipeFactory >> midibt;
    
    // Route 3: Bluetooth → HeatSink (external MIDI control of heat)
    midibt >> pipeFactory >> heatSink;
    
    // Set Bluetooth device name
    midibt.setName("HEAT bit 1 MST");
    
    // Initialize LED controller
    ledController.begin();
    
    // Initialize the Control Surface system
    Control_Surface.begin();
            
    // Initialize CLI
    commandInterface.begin();
    
    Serial.println("Routing configured:");
    Serial.println("  Route 1: Heat Encoder → CC23 → Bluetooth Out (transmission)");
    Serial.println("  Route 2: Bluetooth In → CC23 → Heat Control (external control)");
    Serial.println("Ready!");
}
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

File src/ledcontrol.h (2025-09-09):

#pragma once
#include <Arduino.h>
#include <Wire.h>
#include "LEDRingSmall.h"

class LEDController {
public:
    LEDController() : ledRing(ISSI3746_SJ2 | ISSI3746_SJ7), currentEffect(0) {
        // Rainbow colors for each effect
        rainbowColors[0] = 0xFF0000; // Red - CONST_VIBE
        rainbowColors[1] = 0xFF8000; // Orange - PULSE  
        rainbowColors[2] = 0xFFFF00; // Yellow - RAMP_UP
        rainbowColors[3] = 0x00FF00; // Green - TWO_PULSE
        rainbowColors[4] = 0x0080FF; // Blue - STRONG_BUZZ
        rainbowColors[5] = 0x8000FF; // Purple - PULSE_PURR
    }
    
    void begin() {
        Wire.begin();
        Wire.setClock(400000);
        
        ledRing.LEDRingSmall_Reset();
        delay(20);
        
        ledRing.LEDRingSmall_Configuration(0x01);
        ledRing.LEDRingSmall_PWMFrequencyEnable(1);
        ledRing.LEDRingSmall_SpreadSpectrum(0b0010110);
        ledRing.LEDRingSmall_GlobalCurrent(0x10);
        ledRing.LEDRingSmall_SetScaling(0xFF);
        ledRing.LEDRingSmall_PWM_MODE();
        
        updateDisplay(0);
    }
    
    void updateDisplay(int effectIndex) {
        //if (effectIndex != currentEffect) {
            currentEffect = effectIndex;
            
            // Map effect index to LED positions going clockwise from LED 23
            // Effect 0: LEDs 23,22,21,20  Effect 1: LEDs 19,18,17,16  etc.
            uint8_t startLED = 23 - (effectIndex * 4);
            
            for (uint8_t i = 0; i < 24; i++) {
                // Check if this LED should be lit for current effect
                bool shouldLight = false;
                for (uint8_t j = 0; j < 4; j++) {
                    uint8_t effectLED = (startLED - j + 24) % 24;
                    if (i == effectLED) {
                        shouldLight = true;
                        break;
                    }
                }
                
                if (shouldLight) {
                    ledRing.LEDRingSmall_Set_RGB(i, rainbowColors[effectIndex]);
                } else {
                    ledRing.LEDRingSmall_Set_RGB(i, 0x000000);
                }
            }
        //}
    }
    
    /**
     * @brief Update LED display for heat level visualization
     * 
     * Creates a line segment from LED 23 to current heat level with gradient (clockwise):
     * - LED 23: Blue (0x0000FF) - start position
     * - LED 11: Orange (0xFF8000) 
     * - LED 0: Red (0xFF0000) - end position
     * 
     * @param heatLevel Heat level (0-127 CC value)
     */
    void updateHeatDisplay(uint8_t heatLevel) {
        // Map heat level (0-127) to number of LEDs to light (0-23)
        uint8_t numLEDs = (heatLevel * 23) / 127;
        
        for (uint8_t i = 0; i < 24; i++) {
            // Calculate position from start (LED 23 going clockwise to LED 0)
            uint8_t positionFromStart = (24 - 1 - i) % 24; // LED 23=0, LED 22=1, ..., LED 0=23
            
            if (positionFromStart <= numLEDs) {
                // Light up LED with gradient color based on position from start
                ledRing.LEDRingSmall_Set_RGB(i, calculateHeatGradientColor(positionFromStart));
            } else {
                // Turn off LED
                ledRing.LEDRingSmall_Set_RGB(i, 0x000000);
            }
        }
    }
    
    /**
     * @brief Update LED display for air level visualization with center-based display
     * 
     * Creates a center-based visualization:
     * - LED 0 (12 o'clock): Center position (CC 64 = stopped)
     * - LEDs 1-12 (clockwise): Inflation side (CC 65-127)
     * - LEDs 23-13 (counterclockwise): Deflation side (CC 63-0)
     * 
     * @param airLevel Air level (0-127 CC value, 64 = center/stopped)
     */
    void updateAirDisplay(uint8_t airLevel) {
        // Clear all LEDs first
        for (uint8_t i = 0; i < 24; i++) {
            ledRing.LEDRingSmall_Set_RGB(i, 0x000000);
        }
        
        if (airLevel == 64) {
            // Center position - light only LED 0 with white
            ledRing.LEDRingSmall_Set_RGB(0, 0xFFFFFF);
            
        } else if (airLevel > 64) {
            // Inflation mode (65-127) - counterclockwise from center
            uint8_t inflationLevel = airLevel - 64; // 1-63
            uint8_t numLEDs = (inflationLevel * 12) / 63; // Map to 0-12 LEDs
            
            // Always light center LED
            ledRing.LEDRingSmall_Set_RGB(0, 0xFFFFFF);
            
            // Light inflation LEDs (23-13 counterclockwise)
            for (uint8_t i = 1; i <= numLEDs; i++) {
                uint8_t ledIndex = (24 - i) % 24; // LED 23, 22, 21, ..., 13
                // Red color for inflation
                ledRing.LEDRingSmall_Set_RGB(ledIndex, 0xFF0000);
            }
            
        } else {
            // Deflation mode (0-63) - clockwise from center
            uint8_t deflationLevel = 63 - airLevel; // 0-63 reversed
            uint8_t numLEDs = (deflationLevel * 12) / 63; // Map to 0-12 LEDs
            
            // Always light center LED
            ledRing.LEDRingSmall_Set_RGB(0, 0xFFFFFF);
            
            // Light deflation LEDs (1-12 clockwise)
            for (uint8_t i = 1; i <= numLEDs; i++) {
                // Blue color for deflation
                ledRing.LEDRingSmall_Set_RGB(i, 0x0000FF);
            }
        }
    }
    
    void refresh() {
        ledRing.LEDRingSmall_GlobalCurrent(0x10);
        ledRing.LEDRingSmall_PWM_MODE();
    }

private:
    LEDRingSmall ledRing;
    uint32_t rainbowColors[6];
    int currentEffect;
    
    /**
     * @brief Calculate gradient color for heat display
     * 
     * Creates smooth gradient: Blue (LED 0) → Orange (LED 12) → Red (LED 23)
     * 
     * @param ledIndex LED position (0-23)
     * @return 24-bit RGB color value
     */
    uint32_t calculateHeatGradientColor(uint8_t ledIndex) {
        uint8_t r, g, b;
        
        if (ledIndex <= 12) {
            // First half: Blue → Orange (0x0000FF → 0xFF8000)
            float ratio = (float)ledIndex / 12.0f;
            r = (uint8_t)(0x00 + ratio * (0xFF - 0x00));
            g = (uint8_t)(0x00 + ratio * (0x80 - 0x00));
            b = (uint8_t)(0xFF - ratio * (0xFF - 0x00));
        } else {
            // Second half: Orange → Red (0xFF8000 → 0xFF0000)
            float ratio = (float)(ledIndex - 12) / 11.0f;
            r = 0xFF; // Stay at max red
            g = (uint8_t)(0x80 - ratio * (0x80 - 0x00));
            b = 0x00; // Stay at min blue
        }
        
        return ((uint32_t)r << 16) | ((uint32_t)g << 8) | b;
    }
};

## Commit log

2025-05-16 led ring works example
2025-06-09 pump default off
2025-08-27 led ring and knob pins and midi name updated to post-summer pcb
2025-08-27 Added new GPIO pins because of PCB redesign and fixed esp32 version (6.11.0).
2025-08-28 Change pump/valve GPIO configuration. Matches now PCB labels (M1-M4)
2025-09-03 switch effect with visual feedback and full rotation
2025-09-05 Correct mapping of max pressure. Tiny delay in loop for stability. good enough for now.
2025-09-05 new calibration value for the new fsr (firmware to be updated in actual hbit)
2025-09-05 first go at heat bit
2025-09-06 Update main_heat_bit.cpp
    added missing pipe from control surface to heatSink
    [main_heat_bit.cpp]
2025-09-08 adjusted multiplier, commented out drv2605 driver
2025-09-08 led correct for heat
    [ledcontrol.h, main_heat_bit.cpp]
2025-09-08 heat limiting
2025-09-08 heat visualization tool
2025-09-09 pressure sensor integrated
2025-09-11 moved cc 23->24 and 24->25 + added button on air bit (but not yet working)
2025-09-23 fixed button
2025-09-30 changed to button getState to Falling. Works now.
2026-01-13 update heat and vibe device names; adjust FSR max pressure value
2026-01-13 update README; modify haptic effects and air/heat bit configurations
2026-01-13 update HEAT_PIN to correct GPIO pin for MOSFET M1
    [main_heat_bit.cpp]
2026-02-12 added 3mf files for 3d printing
    [HBL KNOBS_6x.3mf, HBL_AIR.3mf, HBL_PUCK.3mf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]
